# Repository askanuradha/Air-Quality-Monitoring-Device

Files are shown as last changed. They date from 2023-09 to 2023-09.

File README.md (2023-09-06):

# Air Quality Monitoring Device
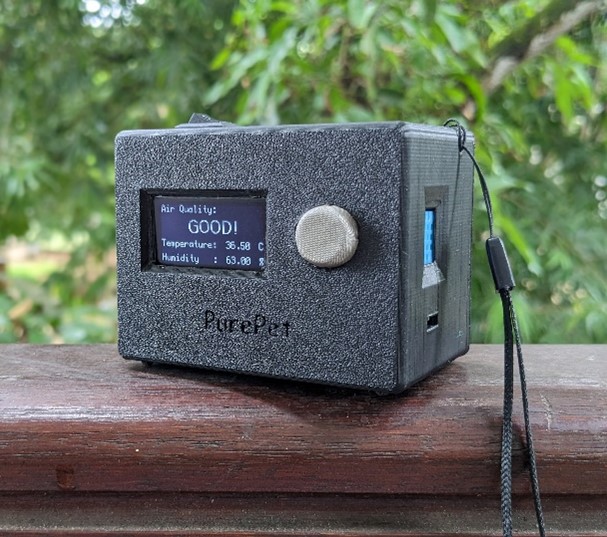
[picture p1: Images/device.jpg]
Device picture


## Overview
This individual project relate to the EN2160-Electronic Design Realization module in semester 4. The device aims to ensure the accurate measurement of key air quality parameters, including carbon dioxide (CO2) levels, temperature, and humidity. The device contains a display and it shows the air quality, humidity percentage, and temperature. The device is easy to operate, no need to calibrate after starting up, it can work and detect measurements automatically.
## Product Details
### Specifications
* Operating temperature - 0 C to 70 C
*	Rechargeable and Compact Size Charging – micro-USB interface with 500mAh battery
*	1.34” inch LED display 
*	CO2 detection range – 100ppm to 10000ppm 
*	CO2 detection Sensitivity – 5ppm 
*	CO2 Accuracy - ± 30ppm 
*	Humidity detection range – 20 – 90% RH 
*	Humidity detection Sensitivity – 1%RH 
*	Humidity Accuracy - ± 5%RH 
*	Temperature detection Range - 0 oC to 50 oC 
*	Temperature detection Sensitivity – 1 oC 
*	Temperature Accuracy - ± 1 oC
*	Size – width = 4.5 cm, length = 8 cm, height = 6 cm
### Features
* The device is small and lightweight so it can place anywhere in a closed area.
* The device consist of a rechargeable battery.
* Three sensors are responsible for collecting and analyzing air parameters to make informed decisions.
## Design Procedure
### Technical Details
The air quality monitoring system using various sensors and an Atmega328P microcontroller. The system will measure air quality parameters, providing real-time data for analysis and decision-making. To power the system, a step-up converter and TP4056 module will be utilized to efficiently manage energy resources.
* **Atmega328P Microcontroller :** The central processing unit responsible for data collection, analysis, and decision-making and Interfaces with various sensors to acquire data.
* **MQ135 Gas Sensor :** Measures the concentration of various gases, including volatile organic compounds (VOCs) and carbon dioxide (CO2) and provides air quality information.
* **DHT11 Temperature and Humidity Sensor :** Monitors ambient temperature and humidity levels.
* **Optical Dust Sensor :** Detects particulate matter (PM) levels in the air and offers insights into air cleanliness and pollution.
* **Step-Up Converter :** Boosts voltage from a TP4056 output to power the system components and ensures stable voltage supply.
* **TP4056 Module :** Manages the charging and protection of the Li-ion battery and provides safe and efficient energy storage.
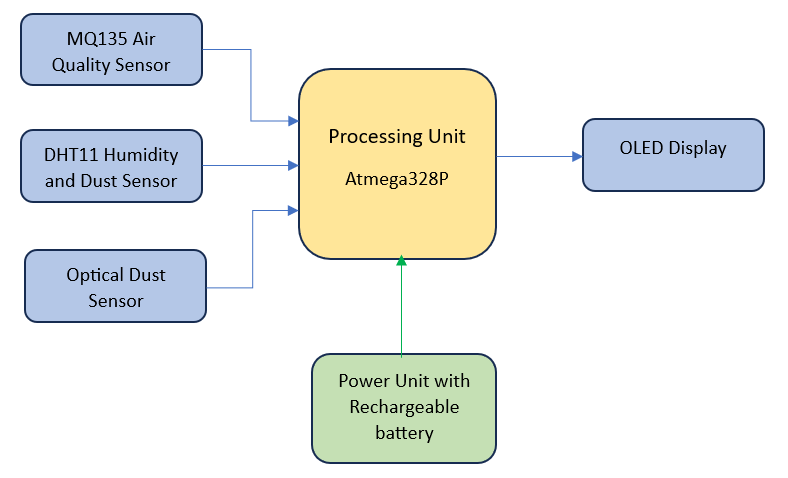
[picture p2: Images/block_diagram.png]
Block Diagram


### Circuit Design
The following Schematic diagram consists of the circuit of the PCB and note that it does not include the modules which I used in the project. (i.e. Not included the Step up boost converter, TP4056 Module, Li-ion Battery)
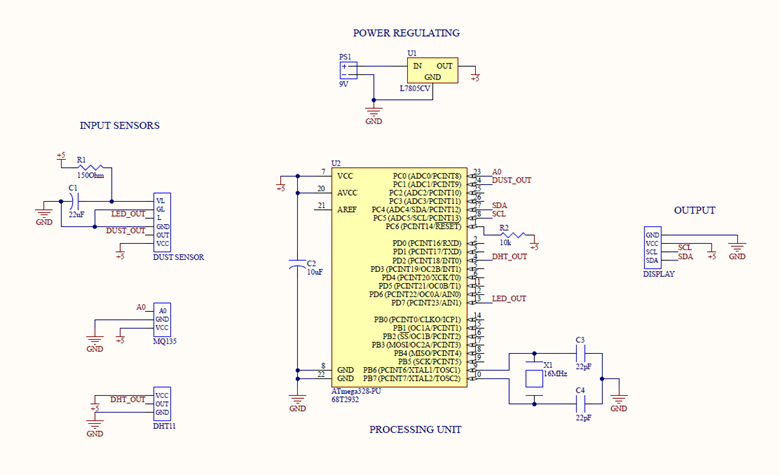
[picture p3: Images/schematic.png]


### PCB Design
The PCB was designed using Altium Designer Software, and it is a two-layer PCB configuration.
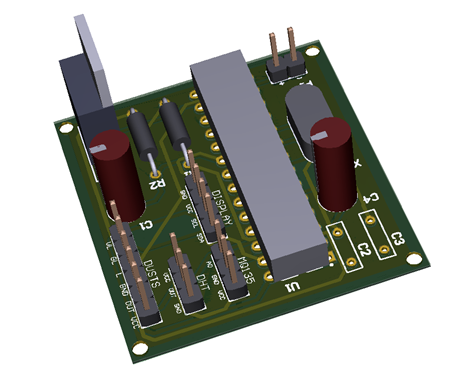
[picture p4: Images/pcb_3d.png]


### Enclosure Design
The enclosure was designed using SolidWorks software and consists of two parts. These parts are securely connected through the use of nuts.
<div align="center">
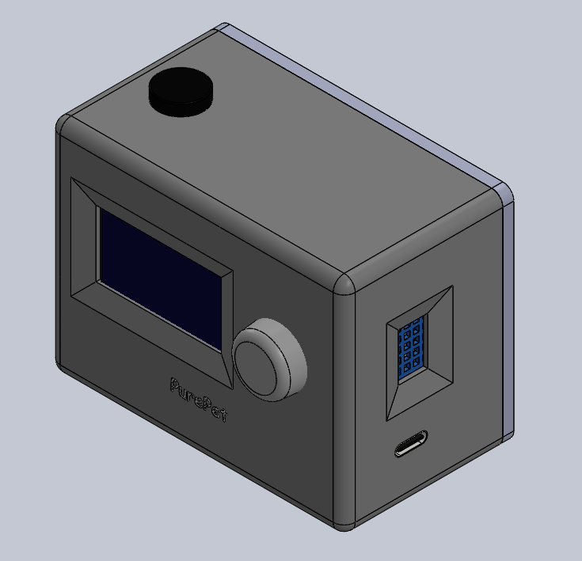
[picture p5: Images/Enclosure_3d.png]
  
  
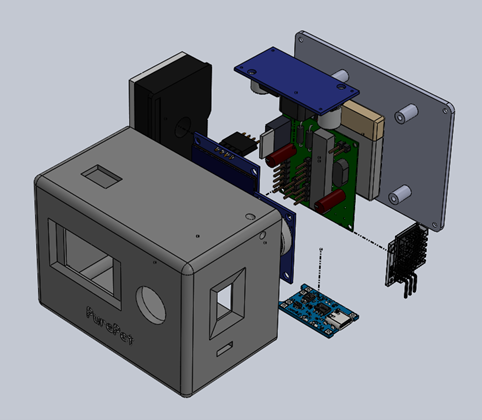
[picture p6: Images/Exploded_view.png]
  
</div>

## Validation
Verified that the sensors (MQ135, DHT11, Optical Dust Sensor) provide accurate data readingsand confirmed that the microcontroller (Atmega328P) correctly processes and displays air quality parameters. Checked that the power management components (Step-Up Converter, TP4056 Module) operate efficiently and safely.
## Conclusion
The development and implementation of the Air Quality Monitoring System with the Atmega328P Microcontroller have yielded a robust and functional solution for real-time air quality assessment. This project successfully integrated a range of components, including the MQ135 gas sensor, DHT11 temperature and humidity sensor, optical dust sensor, and power management modules.

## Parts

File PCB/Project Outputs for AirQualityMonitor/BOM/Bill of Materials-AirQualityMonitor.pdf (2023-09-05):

Created by FEDEVEL | Motherboard, Processor and Microcontroller Board Design | http://www.fedevel.com
Component list | Bill of Materials for Project [AirQualityMonitor.PrjPcb] (No PCB Document Selected)
Source Data From: | AirQualityMonitor.PrjPcb | Contact:
Project: | AirQualityMonitor.PrjPcb | AK Anuradha
Variant: | None | anuradhaak.20@uom.lk | EDR Project

### GitHub - https://github.com/askanuradha

Report Date: | 4/23/2023 | 10:38 AM
Print Date: | 23-Apr-23 | 10:50:06 AM
# | Category | Manufacturer 1 | Manufacturer Part Number 1 | Footprint | Description | Quantity | Supplier 1 | Supplier Part Number 1

Supplier
Order Qty
1

Supplier
Stock 1

Supplier
Unit Price 1

Supplier
Subtotal 1

Supplier
Currency 1
1 | Microcontrollers | Microchip | ATMEGA328PU | 28P3 | 8-bit AVR Microcontroller, 32KB Flash, 1KB
| | | | | EEPROM, 2KB SRAM, 28-pin PDIP, Industrial Grade (-40°C to 85°C)
1 | Avnet | 68T2932 | 1 | 398 | 2.61 | 2.61 | USD
2 3 | Voltage Regulators | STMicroelectronics | L7805CV | TO220 | Positive Voltage Regulator, 5V, 3-Pin TO-220 | 1 | Digi-Key | 497-1443-5-ND | 1 | 41281 | 0.69 | 0.69 | USD
| Through-Hole Resistors | Ohmite | OC1K151E-TR | RESI | Res 150 Ohm 10% 1.2W Axial | 1 | Mouser | 588-OC1K151E-TR | 1 | 1000 | 4.62 | 4.62 | USD
4 5 | Sensors | SparkFun | SEN-17049 | MQ135 | Smoke Sensor - MQ-2 | 1 | Digi-Key | 1568-SEN-17049-ND | 1 | 46 | 5.50 | 5.50 | USD
| Aluminum Electrolytic Capacitors | Rubycon | 450BXC10MEFC10X20 | 10uF | BXC Series 450 V 10 µF 10x20mm Aluminum Electrolytic Capacitor | 1 | Digi-Key | 1189-1894-ND | 1 | 253692 | 0.71 | 0.71 | USD
6 7 | Aluminum Electrolytic Capacitors | Rubycon | 450BXW22MEFR12.5X20 | 10uF | Cap Aluminum 22uF 450V 20% (12.5 X 20mm) Radial Aluminum Cylindrical Can 5mm 280mA 10000 hr 105°C Bulk | 1 | Digi-Key | 1189-2936-ND | 1 | 99001 | 1.59 | 1.59 | USD
| Batteries and Accessories | Adafruit Industries | 1578 | POWER | Lithium Ion Polymer Battery - 3.7v 500mAh | 1 | Digi-Key | 1528-1841-ND | 1 | 826 | 7.95 | 7.95 | USD
8 9 | Crystals and Oscillators | Diodes | GB1600032 | GB1600032 | Crystal 16MHz ±30ppm (Tol) ±30ppm (Stability) 30pF FUND 40Ohm 2-Pin Thru-Hole Bag | 1 | Digi-Key | GB1600032-ND | 1 | 533 | 0.52 | 0.52 | USD
| LCD, OLED, Graphic Displays | Adafruit Industries | 938 | DISPLAY | Monochrome 1.3 128x64 OLED graphic display -STEMMA QT / Qwiic | 1 | Digi-Key | 1528-1512-ND | 1 | 36 | 19.95 | 19.95 | USD
10 11 | Mica Capacitors | Cornell Dubilier | CD5EC220JO3F | 22pF | Capacitor; Mica; Cap 22pF; Tol 5%; Radial Miniature DIPped; Vol-Rtg 300VDC; LS 3.0mm | 2 | Digi-Key | 338-2650-ND | 2 | 978 | 3.82 | 7.64 | USD
| Sensors | Socle Technology | GP2Y1010AU0F | DUSTS | GP2Y1010AU0F Series 5.5 V 10 mA Compact Optical Dust Sensor (46 × 30 × 17.6 mm) | 1 | Digi-Key | 1855-1012-ND | 1 | 2206 | 12.37 | 12.37 | USD
12 13 | Sensors | DFRobot | DFR0067 | DHT | Temperature Humidity Sensor, Arduino Rohs Compliant: Yes | 1 | Digi-Key | 1738-1089-ND | 1 | 16 | 7.90 | 7.90 | USD
| Through-Hole Resistors | Stackpole Electronics | CF14JT10K0 | RESI | Res Carbon Film 10K Ohm 5% 0.25W(1/4W) -500ppm/•Ž to 0p| | 1 | Digi-Key | CF14JT10K0CT-ND | 1 | 4110 | 0.10 | 0.10 | USD
| | | | | | 14 | | | 14 | 72.15
Approved | | | | Notes Price for 1pcs | | | | | | | | USD
1 pcs: | Total | USD
72.15

72.15

4/23/2023 | 1/1

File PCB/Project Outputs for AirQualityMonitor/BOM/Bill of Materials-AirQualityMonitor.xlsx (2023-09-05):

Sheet: Part List Report
 | Component list |  |  | Bill of Materials for Project [AirQualityMonitor.PrjPcb] (No PCB Document Selected)
 | Source Data From: | AirQualityMonitor.PrjPcb |  |  | Contact:
 | Project: | AirQualityMonitor.PrjPcb |  |  | AK Anuradha
 | Variant: | None |  |  | anuradhaak.20@uom.lk |  |  |  | EDR Project
 |  |  |  |  | GitHub - https://github.com/askanuradha
 | Report Date: | 4/23/2023 | 10:38 AM
 | Print Date: | 2023-04-23 | 10:50:06
# | Category | Manufacturer 1 | Manufacturer Part Number 1 | Footprint | Description | Quantity | Supplier 1 | Supplier Part Number 1 | Supplier Order Qty 1 | Supplier Stock 1 | Supplier Unit Price 1 | Supplier Subtotal 1 | Supplier Currency 1
1 | Microcontrollers | Microchip | ATMEGA328PU | 28P3 | 8-bit AVR Microcontroller, 32KB Flash, 1KB EEPROM, 2KB SRAM, 28-pin PDIP, Industrial Grade (-40°C to 85°C) | 1 | Avnet | 68T2932 | 1 | 398 | 2.61 | 2.61 | USD
2 | Voltage Regulators | STMicroelectronics | L7805CV | TO220 | Positive Voltage Regulator, 5V, 3-Pin TO-220 | 1 | Digi-Key | 497-1443-5-ND | 1 | 41281 | 0.69 | 0.69 | USD
3 | Through-Hole Resistors | Ohmite | OC1K151E-TR | RESI | Res 150 Ohm 10% 1.2W Axial | 1 | Mouser | 588-OC1K151E-TR | 1 | 1000 | 4.62 | 4.62 | USD
4 | Sensors | SparkFun | SEN-17049 | MQ135 | Smoke Sensor - MQ-2 | 1 | Digi-Key | 1568-SEN-17049-ND | 1 | 46 | 5.50 | 5.50 | USD
5 | Aluminum Electrolytic Capacitors | Rubycon | 450BXC10MEFC10X20 | 10uF | BXC Series 450 V 10 µF 10x20mm Aluminum Electrolytic Capacitor | 1 | Digi-Key | 1189-1894-ND | 1 | 253692 | 0.71 | 0.71 | USD
6 | Aluminum Electrolytic Capacitors | Rubycon | 450BXW22MEFR12.5X20 | 10uF | Cap Aluminum 22uF 450V 20% (12.5 X 20mm) Radial Aluminum Cylindrical Can 5mm 280mA 10000 hr 105°C Bulk | 1 | Digi-Key | 1189-2936-ND | 1 | 99001 | 1.59 | 1.59 | USD
7 | Batteries and Accessories | Adafruit Industries | 1578 | POWER | Lithium Ion Polymer Battery - 3.7v 500mAh | 1 | Digi-Key | 1528-1841-ND | 1 | 826 | 7.95 | 7.95 | USD
8 | Crystals and Oscillators | Diodes | GB1600032 | GB1600032 | Crystal 16MHz ±30ppm (Tol) ±30ppm (Stability) 30pF FUND 40Ohm 2-Pin Thru-Hole Bag | 1 | Digi-Key | GB1600032-ND | 1 | 533 | 0.52 | 0.52 | USD
9 | LCD, OLED, Graphic Displays | Adafruit Industries | 938 | DISPLAY | Monochrome 1.3 128x64 OLED graphic display - STEMMA QT / Qwiic | 1 | Digi-Key | 1528-1512-ND | 1 | 36 | 19.95 | 19.95 | USD
10 | Mica Capacitors | Cornell Dubilier | CD5EC220JO3F | 22pF | Capacitor; Mica; Cap 22pF; Tol 5%; Radial Miniature DIPped; Vol-Rtg 300VDC; LS 3.0mm | 2 | Digi-Key | 338-2650-ND | 2 | 978 | 3.82 | 7.64 | USD
11 | Sensors | Socle Technology | GP2Y1010AU0F | DUSTS | GP2Y1010AU0F Series 5.5 V 10 mA Compact Optical Dust Sensor (46 × 30 × 17.6 mm) | 1 | Digi-Key | 1855-1012-ND | 1 | 2206 | 12.37 | 12.37 | USD
12 | Sensors | DFRobot | DFR0067 | DHT | Temperature Humidity Sensor, Arduino Rohs Compliant: Yes | 1 | Digi-Key | 1738-1089-ND | 1 | 16 | 7.90 | 7.90 | USD
13 | Through-Hole Resistors | Stackpole Electronics | CF14JT10K0 | RESI | Res Carbon Film 10K Ohm 5% 0.25W(1/4W) -500ppm/ to 0p| | 1 | Digi-Key | CF14JT10K0CT-ND | 1 | 4110 | 0.10 | 0.10 | USD
 |  |  |  |  |  | 14 |  |  | 14 |  |  | 72.15
Approved |  |  |  | Notes
 |  |  |  |  |  | 1 | pcs: | Total |  | 72.15 |  | USD
 |  |  |  |  |  |  |  | Price for 1pcs |  | 72.15 |  | USD

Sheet: Project Information
Project Full Path | E:\Semester 4\Electronic design realization\Project PCB\AirQualityMonitor\AirQualityMonitor.PrjPcb
Project Filename | AirQualityMonitor.PrjPcb
Variant Name | None
Data-Source Filename | AirQualityMonitor.PrjPcb
Data-Source Full Path | E:\Semester 4\Electronic design realization\Project PCB\AirQualityMonitor\AirQualityMonitor.PrjPcb
Title | Bill of Materials for Project [AirQualityMonitor.PrjPcb] (No PCB Document Selected)
Total Quantity | 14
Report Time | 10:38 AM
Report Date | 4/23/2023
Report Date & Tine | 4/23/2023 10:38 AM
Output Name | Bill of Materials
Output Type | BomReport
Output Generator Name | BOM
Output Generator Description | Bill of Materials

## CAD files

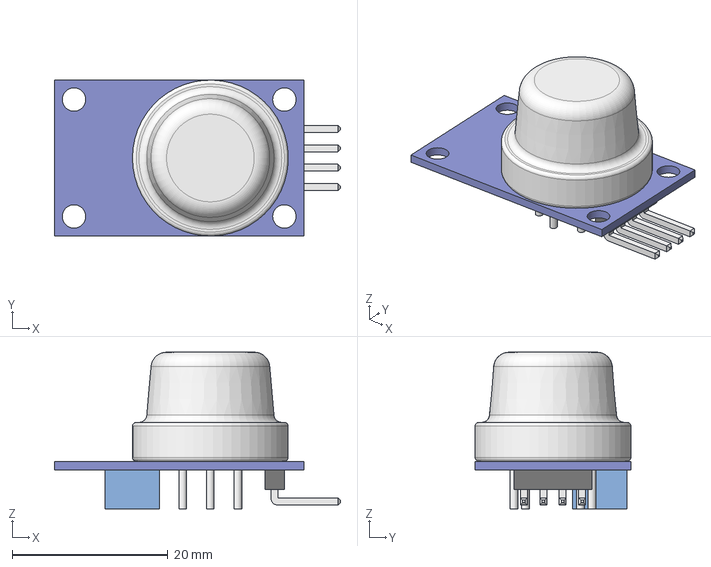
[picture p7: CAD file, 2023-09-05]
Enclosure/MQ135_sensor.step
36.7 x 20.0 x 20.1 mm

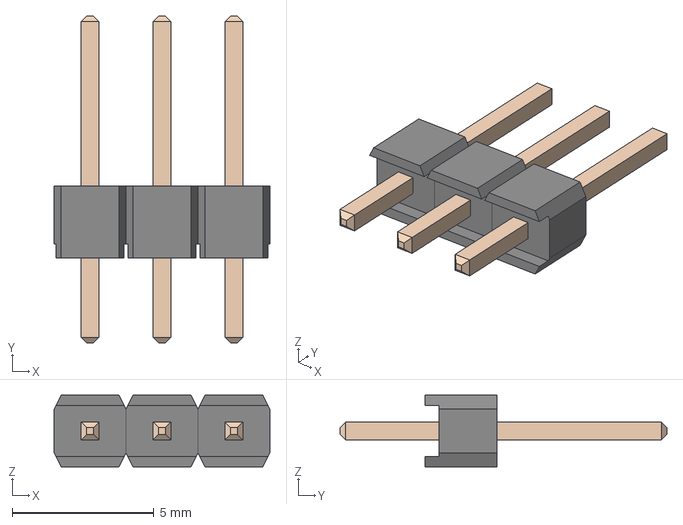
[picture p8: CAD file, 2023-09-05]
PCB/Imports/header-23.snapshot.38/header3pin.stp
7.62 x 11.5 x 2.54 mm
6130xx11121_PIN x 3

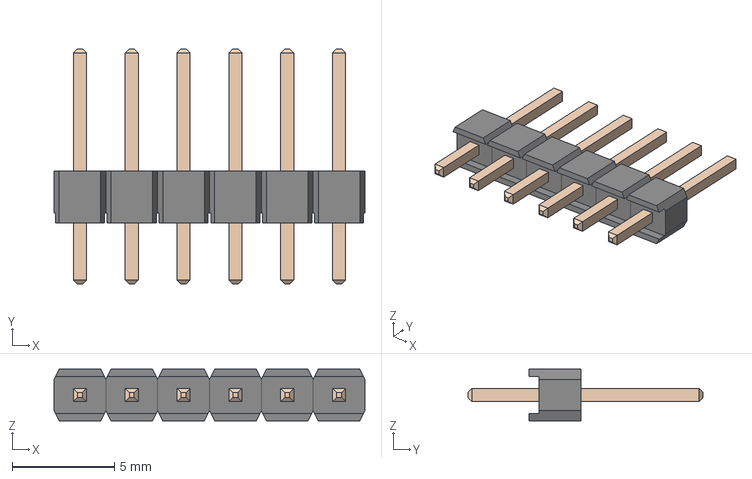
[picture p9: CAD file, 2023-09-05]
PCB/Imports/header6pin.stp
15.2 x 11.5 x 2.54 mm
6130xx11121_PIN x 6

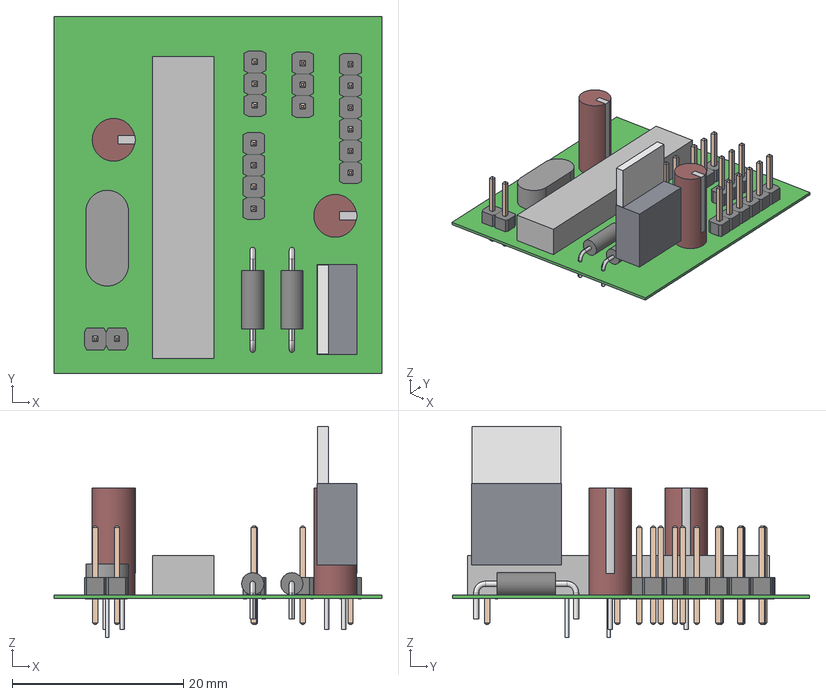
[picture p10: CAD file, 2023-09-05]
PCB/Project Outputs for AirQualityMonitor/ExportSTEP/PCB1.step
38.4 x 41.8 x 24.7 mm
6130xx11121_PIN x 18
YAG_CFR25_YAG x 2
CAP_UEP_5X11_NCH x 2
Leads
Extruded x 3

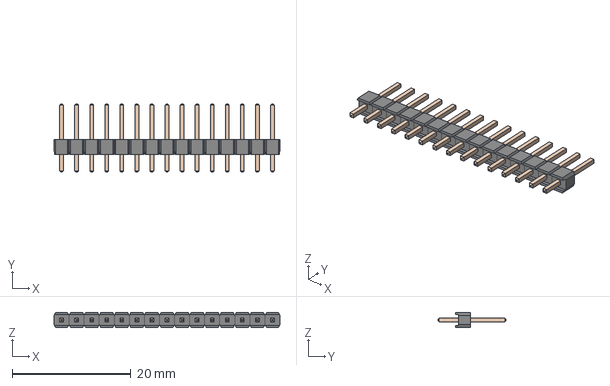
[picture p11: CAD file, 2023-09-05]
PCB/Imports/header-23.snapshot.38/header15pin.stp
38.1 x 11.5 x 2.54 mm
6130xx11121_PIN x 15

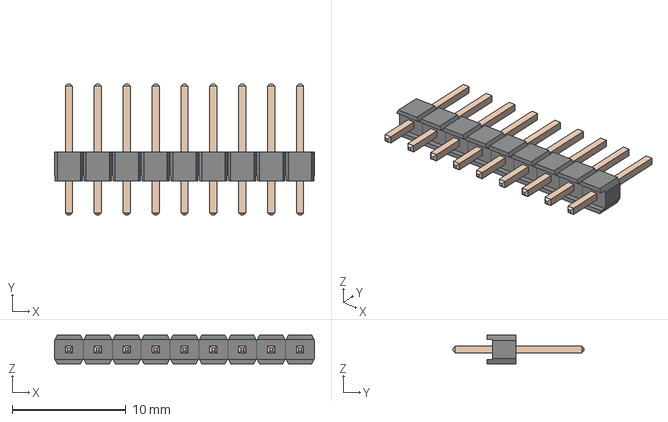
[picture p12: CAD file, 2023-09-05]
PCB/Imports/header-23.snapshot.38/header9pin.stp
22.9 x 11.5 x 2.54 mm
6130xx11121_PIN x 9

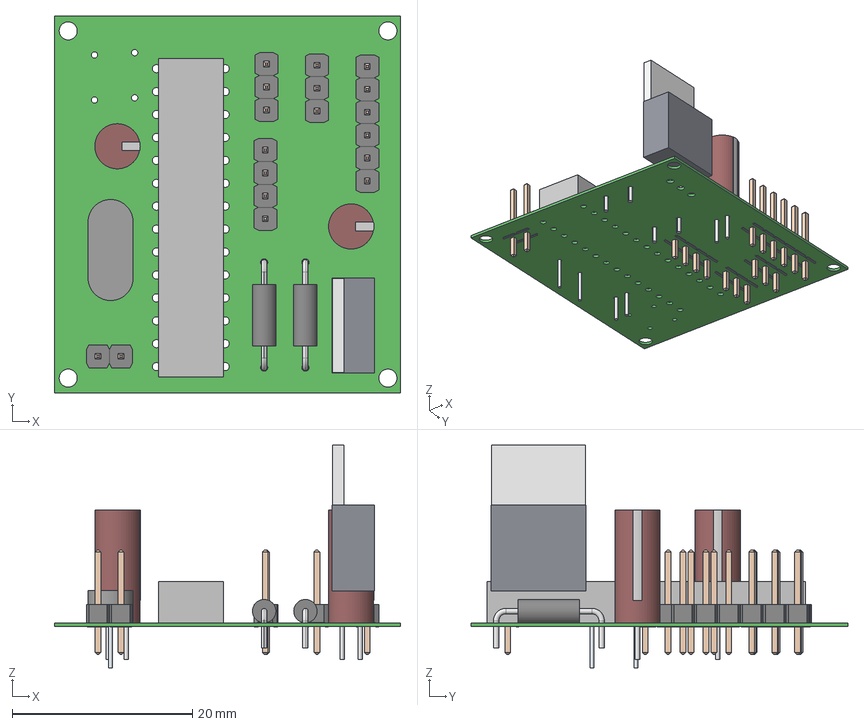
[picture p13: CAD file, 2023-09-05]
Enclosure/PCB1.step
38.4 x 41.8 x 24.7 mm
6130xx11121_PIN x 18
YAG_CFR25_YAG x 2
CAP_UEP_5X11_NCH x 2
Leads
Extruded x 3

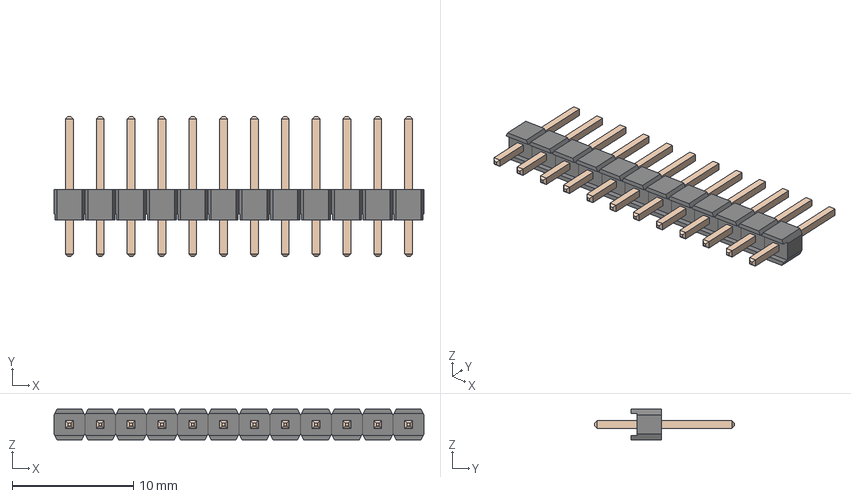
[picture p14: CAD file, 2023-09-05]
PCB/Imports/header-23.snapshot.38/header12pin.stp
30.5 x 11.5 x 2.54 mm
6130xx11121_PIN x 12

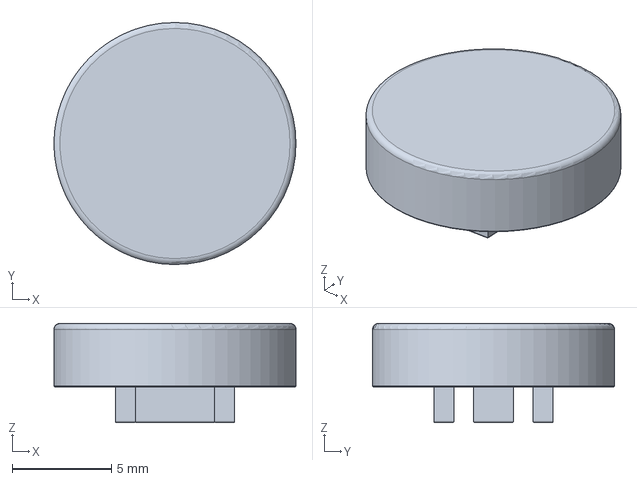
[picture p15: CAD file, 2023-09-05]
Enclosure/button round 12mm cover.step
12.2 x 12.2 x 5.00 mm

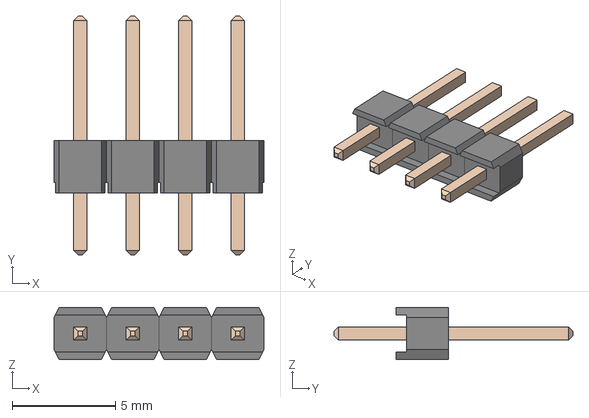
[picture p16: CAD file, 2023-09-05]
PCB/Imports/header-23.snapshot.38/header4pin.stp
10.2 x 11.5 x 2.54 mm
6130xx11121_PIN x 4

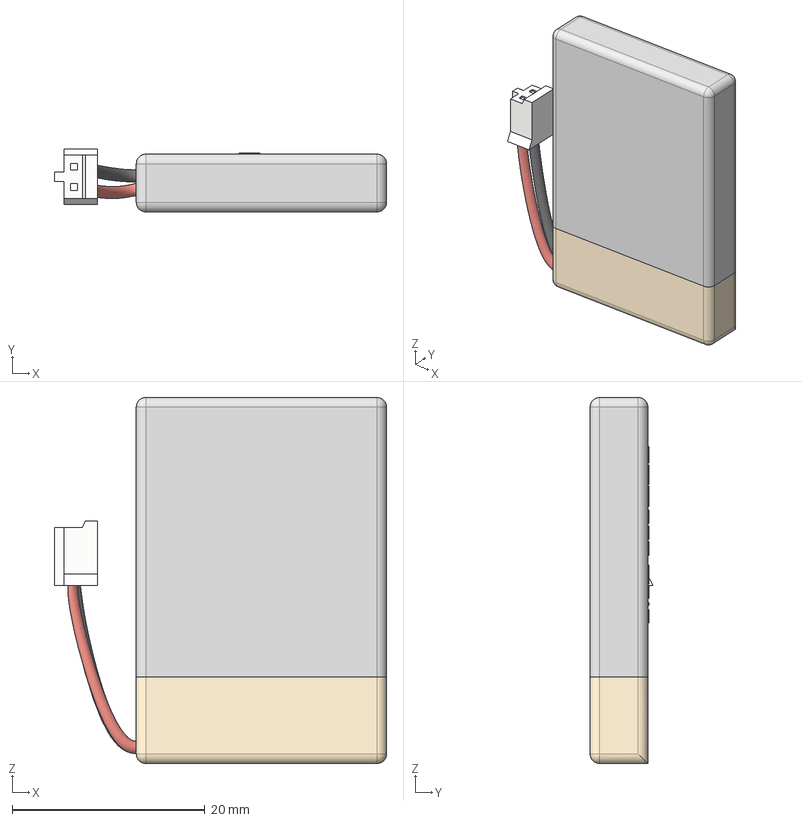
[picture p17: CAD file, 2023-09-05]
Enclosure/3.3V 500Mah Battery v2.step
34.5 x 6.52 x 38.0 mm
Black wIRE
Red Wire
Connector
Text
Text (1)

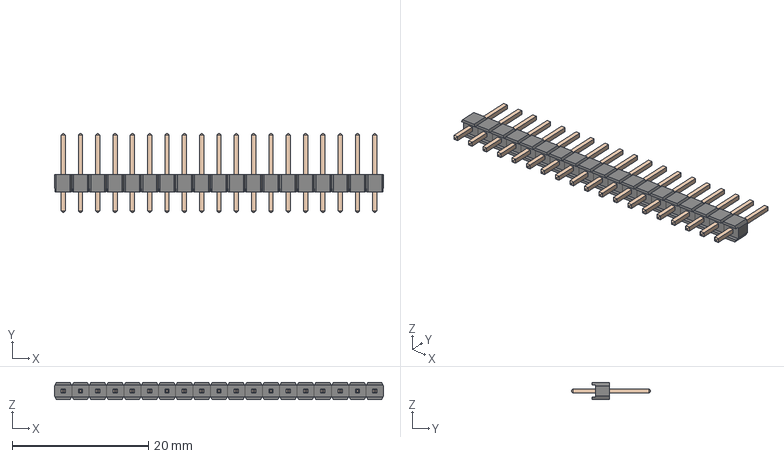
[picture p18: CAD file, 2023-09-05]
PCB/Imports/header-23.snapshot.38/header19pin.stp
48.3 x 11.5 x 2.54 mm
6130xx11121_PIN x 19

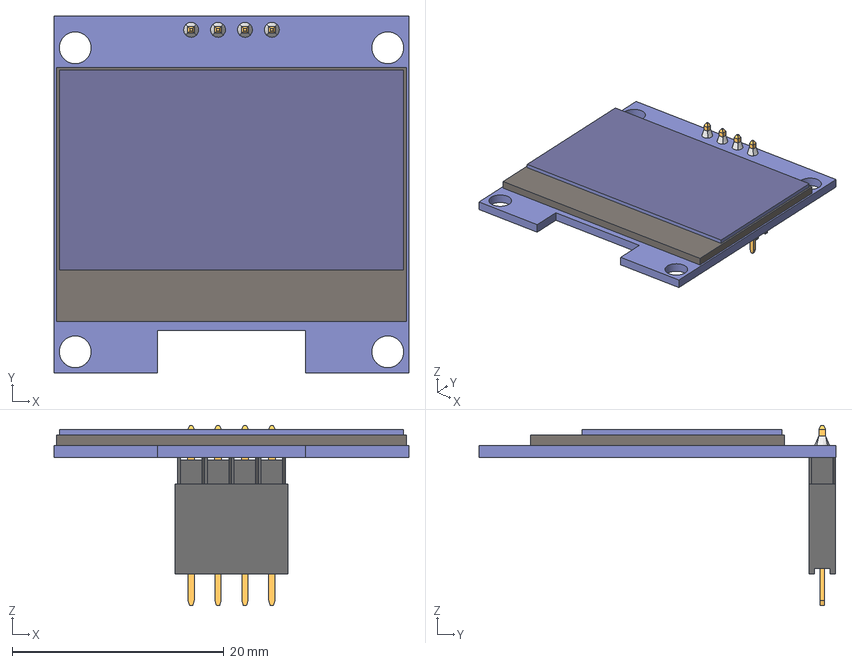
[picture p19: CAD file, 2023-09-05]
Enclosure/OLED I2C 1.3 Inch Display v16.step
33.5 x 33.7 x 17.0 mm
PIN HEADER MALE 2.54MM P4
PIN HEADER FAMALE 2.54MM P4
4 lü Lehim v2

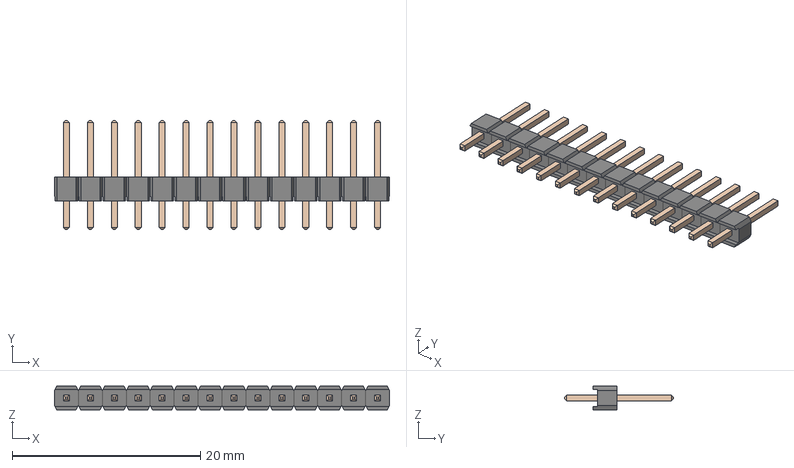
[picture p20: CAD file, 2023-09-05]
PCB/Imports/header-23.snapshot.38/header14pin.stp
35.6 x 11.5 x 2.54 mm
6130xx11121_PIN x 14

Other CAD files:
Enclosure/Dust sensor GP2Y1010AU0F.step
Enclosure/KY-015.step
PCB/Imports/LIB_GB1600032/GB1600032/3D/GB1600032.stp
PCB/Imports/LIB_GB1600032/GB1600032/Allegro/gb1600032.psm
PCB/Imports/LIB_GB1600032/GB1600032/DEHDL/gb1600032/chips/chips.prt
PCB/Imports/header-23.snapshot.38/header10pin.stp
PCB/Imports/header-23.snapshot.38/header11pin.stp
PCB/Imports/header-23.snapshot.38/header13pin.stp
PCB/Imports/header-23.snapshot.38/header16pin.stp
PCB/Imports/header-23.snapshot.38/header17pin.stp
PCB/Imports/header-23.snapshot.38/header18pin.stp
PCB/Imports/header-23.snapshot.38/header1pin.stp
PCB/Imports/header-23.snapshot.38/header20pin.stp
PCB/Imports/header-23.snapshot.38/header2pin.stp
PCB/Imports/header-23.snapshot.38/header5pin.stp
PCB/Imports/header-23.snapshot.38/header7pin.stp
PCB/Imports/header-23.snapshot.38/header8pin.stp

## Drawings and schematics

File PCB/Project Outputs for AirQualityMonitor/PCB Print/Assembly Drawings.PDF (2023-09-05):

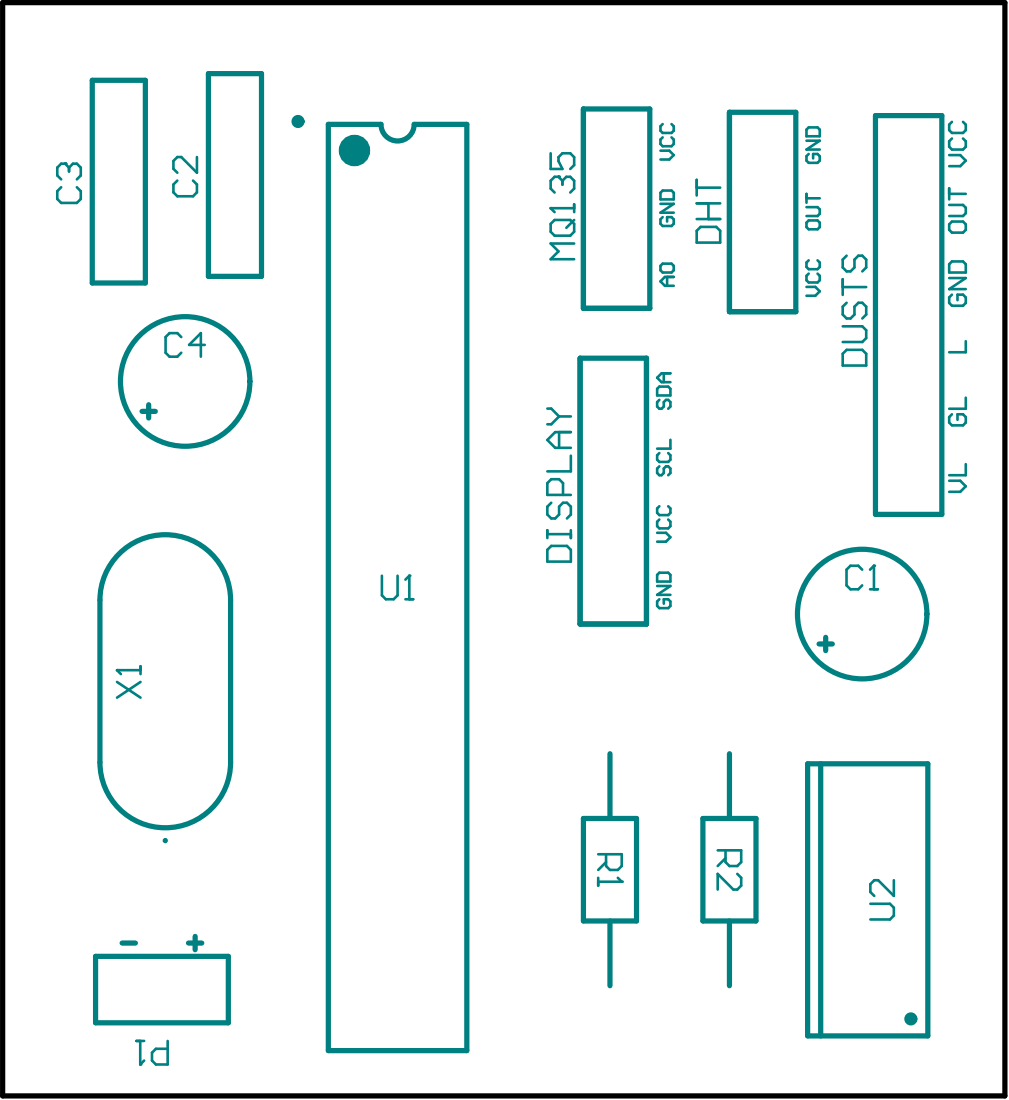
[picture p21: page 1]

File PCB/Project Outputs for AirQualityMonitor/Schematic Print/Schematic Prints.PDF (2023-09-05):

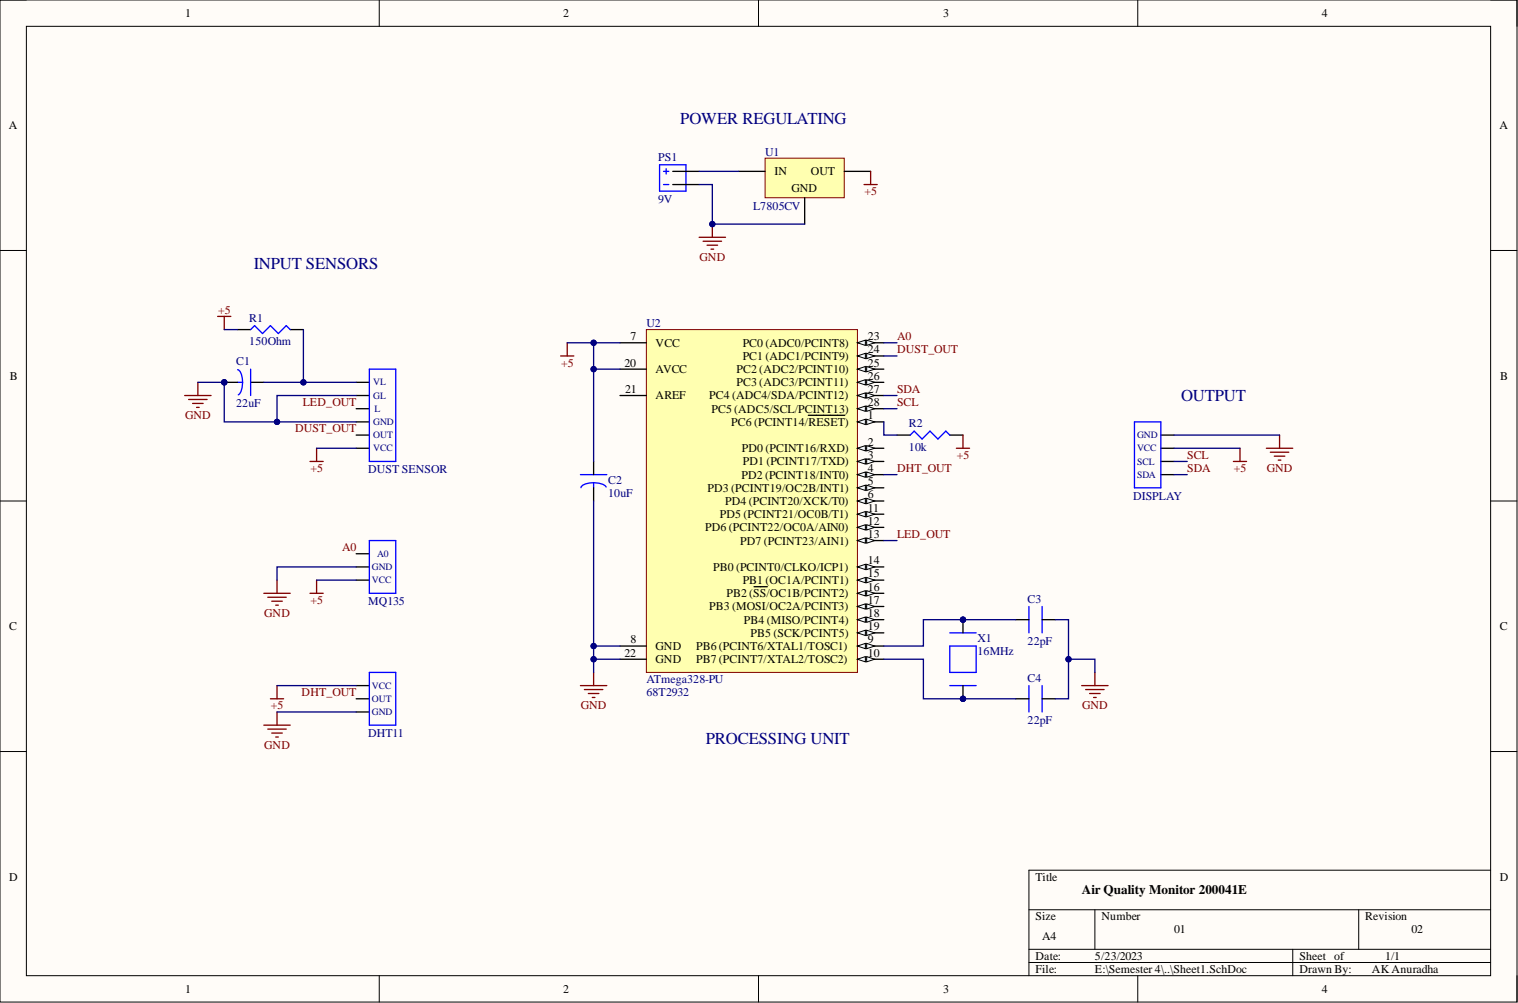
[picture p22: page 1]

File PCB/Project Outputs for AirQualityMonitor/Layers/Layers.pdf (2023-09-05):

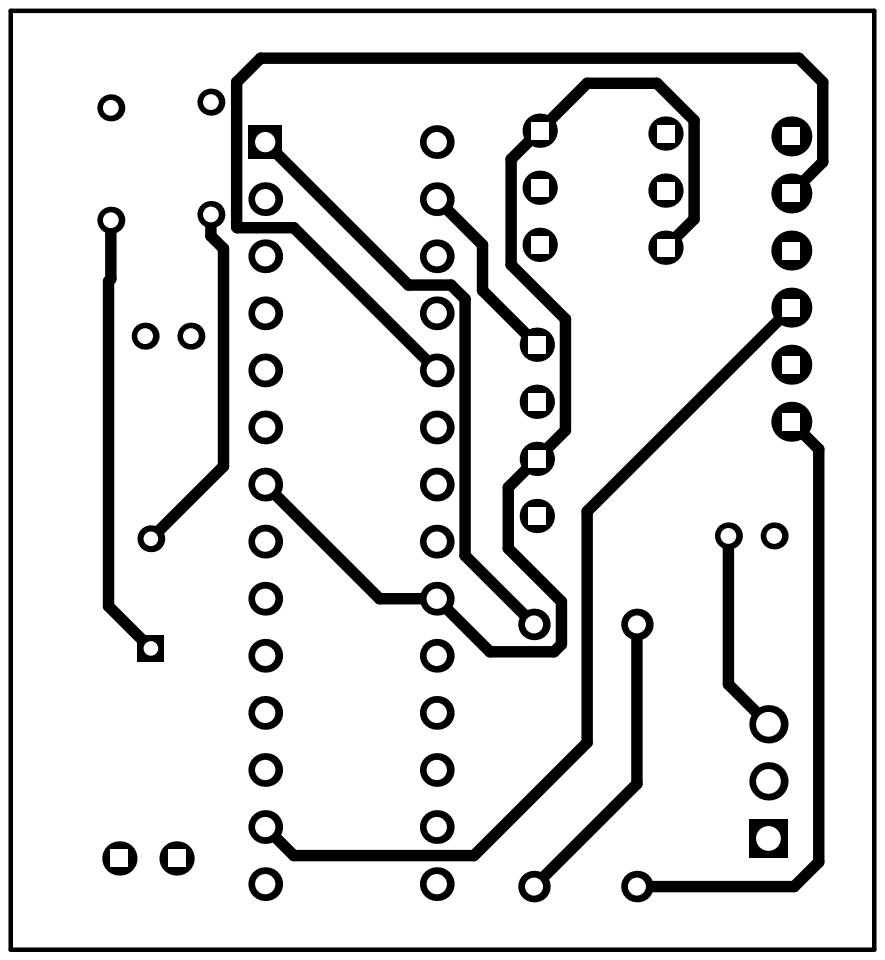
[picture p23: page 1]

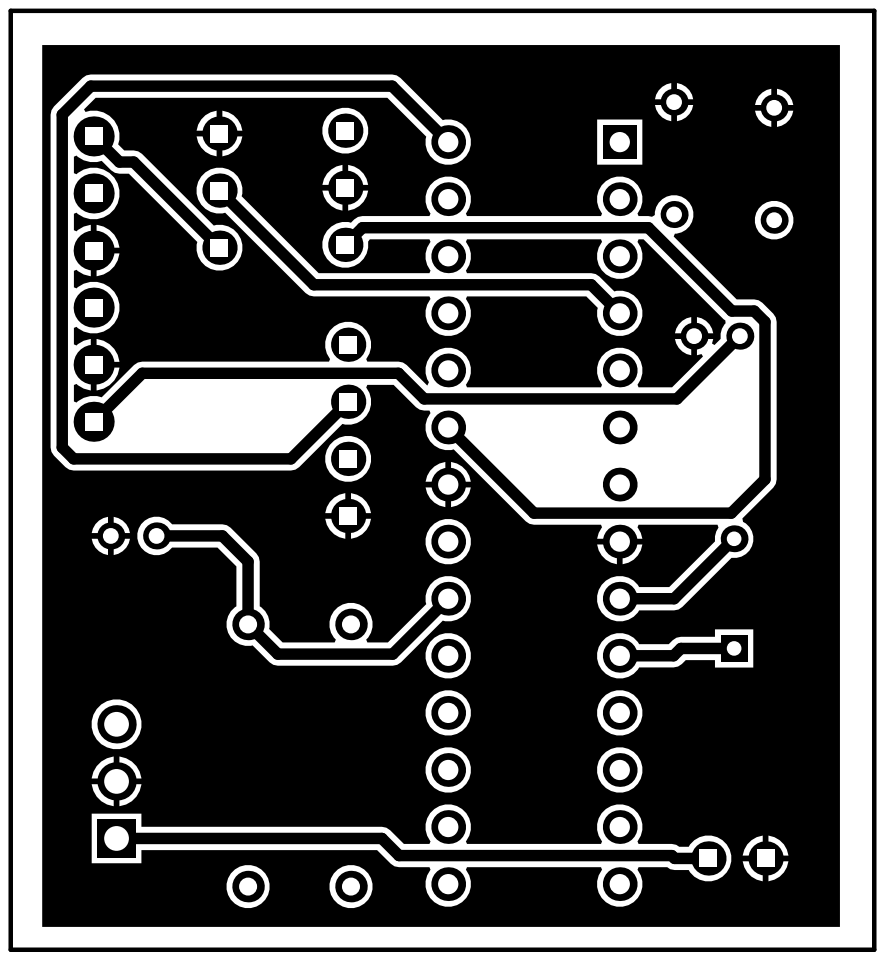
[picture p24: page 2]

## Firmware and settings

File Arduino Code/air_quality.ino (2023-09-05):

#include <SPI.h>
#include <Wire.h>
#include <Adafruit_GFX.h>
#include  <Adafruit_SSD1306.h>
#include <Fonts/FreeSans9pt7b.h>
#include <Fonts/FreeMonoOblique9pt7b.h>
#include "MQ135.h"
#include  <DHT.h>
#define SCREEN_WIDTH 128 // OLED display width, in pixels
#define  SCREEN_HEIGHT 64 // OLED display height, in pixels

#define OLED_RESET     4  // Reset pin # (or -1 if sharing Arduino reset pin)
Adafruit_SSD1306 display(SCREEN_WIDTH,  SCREEN_HEIGHT, &Wire, OLED_RESET);

#define sensor    A0 
#define DHTPIN  2          // Digital pin 2
#define DHTTYPE DHT11     // DHT 11

int gasLevel  = 0;         //int variable for gas level
String quality =""; 
DHT dht(DHTPIN,  DHTTYPE);
MQ135 gasSensor = MQ135(A0);


int measurePin = A1; //Connect dust sensor to Arduino A1 pin
int ledPower = 7;   //Connect 3 led driver pins of dust sensor to Arduino D7

int samplingTime = 280;
int deltaTime = 40;
int sleepTime = 9680;

float voMeasured = 0;
float calcVoltage = 0;
float dustDensity = 0;



void dustSensor() {
  float ppm = gasSensor.getPPM();
  digitalWrite(ledPower,LOW); // power on the LED
  delayMicroseconds(samplingTime);

  voMeasured = analogRead(measurePin); // read the dust value

  delayMicroseconds(deltaTime);
  digitalWrite(ledPower,HIGH); // turn the LED off
  delayMicroseconds(sleepTime);

  // 0 - 5V mapped to 0 - 1023 integer values
  // recover voltage
  calcVoltage = voMeasured * (5.0 / 1024.0);

  // linear eqaution taken from http://www.howmuchsnow.com/arduino/airquality/
  // Chris Nafis (c) 2012
  dustDensity = 170 * calcVoltage - 0.1;

  display.setTextColor(WHITE);
  display.setTextSize(1);
  display.setFont();
  display.setCursor(0, 43);
  display.println("Dust :");
  display.setCursor(40, 43);
  display.println(dustDensity);
  display.setCursor(74, 43);
  display.println("ppm");
  display.setCursor(0,  56);
  display.println("CO2  :");
  display.setCursor(40, 56);
  display.println(ppm);
  display.setCursor(74, 56);
  display.println("ppm");
}

void sendSensor()
{
  float h = dht.readHumidity();
  float t = dht.readTemperature();

  if (isnan(h) || isnan(t)) {
  Serial.println("Failed  to read from DHT sensor!");
    return;
  }
  display.setTextColor(WHITE);
  display.setTextSize(1);
  display.setFont();
  display.setCursor(0, 43);
  display.println("Temp  :");
  display.setCursor(50, 43);
  display.println(t);
  display.setCursor(84, 43);
  display.println("C");
  display.setCursor(0,  56);
  display.println("RH    :");
  display.setCursor(50, 56);
  display.println(h);
  display.setCursor(84, 56);
  display.println("%");
}

void air_sensor()
{
  gasLevel = analogRead(sensor);

  if(gasLevel<181){
    quality = "  GOOD!";
  }
  else if (gasLevel >181 && gasLevel<225){
    quality =  "  Poor!";
  }
  else if (gasLevel >225 && gasLevel<300){
    quality  = "Very bad!";
  }
    else if (gasLevel >300 && gasLevel<350){
    quality  = "ur dead!";
  }
    else{
    quality = " Toxic";   
}
  
  display.setTextColor(WHITE);
  display.setTextSize(1);  
  display.setCursor(1,5);
  display.setFont();
  display.println("Air Quality:");
  display.setTextSize(1);
  display.setCursor(20,23);
  display.setFont(&FreeMonoOblique9pt7b);
  display.println(quality);  
}

void setup() {
  Serial.begin(9600);
  pinMode(sensor,INPUT);
  dht.begin();
  if(!display.begin(SSD1306_SWITCHCAPVCC, 0x3D)) { // Address  0x3D for 128x64
    Serial.println(F("SSD1306 allocation failed"));
}
  display.clearDisplay();
  display.setTextColor(WHITE);
  
  display.setTextSize(2);
  display.setCursor(50, 0);
  display.println("Air");
  display.setTextSize(1);
  display.setCursor(23, 20);
  display.println("Qulaity monitor");
  display.display();
  delay(1200);
  display.clearDisplay();
  
  display.setTextSize(2);
  display.setCursor(50, 20);
  display.println("EDR");
  display.display();
  delay(1000);
  display.clearDisplay();    
}

void loop() {
  display.clearDisplay();
  air_sensor();
  sendSensor();
  display.display();
  delay(3000);
  display.clearDisplay();
  air_sensor();
  dustSensor();
  display.display();
  delay(3000);
}
